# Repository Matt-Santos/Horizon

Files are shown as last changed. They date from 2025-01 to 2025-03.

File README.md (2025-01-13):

# Horizon (Planning Stage)

## Project Description
A high precision experimental bicopter with customized control system. 
 
## Research Hypothisis
A bicopter design when implemented using an unstable thrust to center of mass point can perform with equivalent mobility to that of the simlified quadcopter version through the use of an advanced control system. 

## Evaluation Criteria
To test this theory I purposely design an unstable thrust/weight configuration to enhance reactibility/mobility of the traditional bicopter configuration to avoid the added requirement of pitch control and improve overall efficiency.

## Todo List
- [ ] Perform Literature Review
- [ ] Identify Key Varriables
- [ ] Create Mathematical Model
- [ ] Perform Model Simulations
- [ ] Fabricate a Design Prototype
- [ ] Perform Experiemental Evaluation
- [ ] Create Publication of Findings

## Potential Usage Applications
- Atmospheric Monitoring
- Camera Mapping
- Antenna Testing

## Hardware Components
- [EMAX MT2213 935KV](https://emaxmodel.com/products/emax-mt2213-935kv-multicopter-brushless-motor) Multicopter Brushless Motor
- EMAX1045 Propeller
- [EMAX Simon Series 20A](https://emaxmodel.com/products/emax-simon-series-20a-for-muti-copter)

## Extra Notes

### Transport Canadian Drone Requirements

Note: Can avoid the AOL if takeoff weight is < 250g (goal)

Advanced Operations Licence (AOL)
- [ ] Advanced Drone Pilot Certificate
	- Pass Small Advanced Exam
	- Pass Flight Review
- [ ] Registered and Marked Drone
- [ ] RPAS Flight Authorization (for Controlled Airspace)
- [ ] RPAS Safety Declaration
	- Conforms to [Advisory Circular (AC) No. 922-001](https://tc.canada.ca/en/aviation/reference-centre/advisory-circulars/advisory-circular-ac-no-922-001)

Flight Restrictions (with AOL)
- Max Height AGL = 122m
- Operations in controlled and uncontrolled airspace
- Operations near people: less than 30 meters (100 feet) but more than 5 meters (16.4 feet) horizontally
- Operations over people: less than 5 meters (16.4 feet) horizontally
- Operations less than 3 nautical miles from a certified airport or a military aerodrome
- Operations less than 1 nautical mile from a certified heliport

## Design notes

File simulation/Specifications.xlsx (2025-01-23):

Current (A) | Thrust (G) | Power (W) | Efficiency (G/W) | Speed (RPM)
0.01 | 0 | 0 |  | 0
1 | 130 | 11 | 11.8 | 2940
2 | 220 | 22 | 10.0 | 3860
3 | 290 | 33 | 8.8 | 4400
4 | 360 | 44 | 8.2 | 4940
5 | 430 | 55 | 7.8 | 5340
6 | 490 | 66 | 7.4 | 5720
7 | 540 | 77 | 7.0 | 5980
8 | 580 | 88 | 6.6 | 6170
9 | 620 | 99 | 6.3 | 6410
9.5 | 640 | 105.5 | 6.1 | 6530
Note: Assumes drives voltage of 11.1V

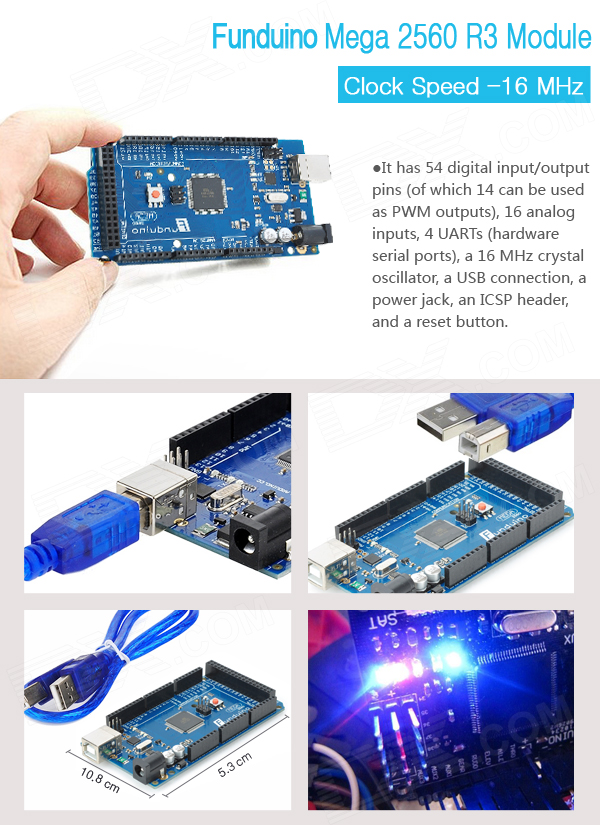
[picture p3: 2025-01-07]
documents/Refrences/sku_256335_01.jpg

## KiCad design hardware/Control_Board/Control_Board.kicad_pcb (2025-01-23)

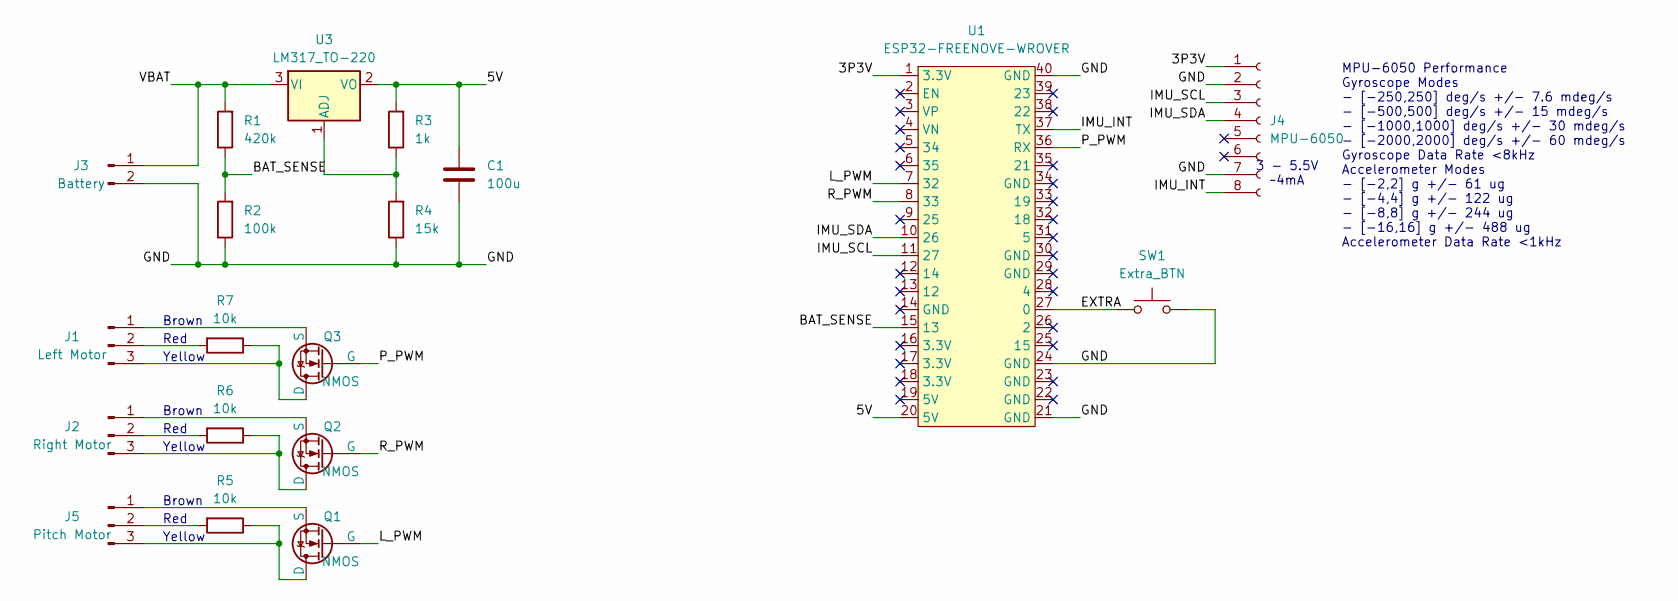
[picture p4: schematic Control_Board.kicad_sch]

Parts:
C1: 100u; C_Disc_D3.0mm_W1.6mm_P2.50mm
J1: Left Motor; PinHeader_1x03_P2.54mm_Vertical
J2: Right Motor; PinHeader_1x03_P2.54mm_Vertical
J3: Battery; PinHeader_1x02_P2.54mm_Vertical
J4: MPU-6050; PinSocket_1x08_P2.54mm_Vertical
J5: Pitch Motor; PinHeader_1x03_P2.54mm_Vertical
Q1, Q2, Q3: NMOS; PinHeader_1x03_P2.54mm_Vertical
R1: 420k; R_Axial_DIN0207_L6.3mm_D2.5mm_P10.16mm_Horizontal
R2: 100k; R_Axial_DIN0207_L6.3mm_D2.5mm_P10.16mm_Horizontal
R3: 1k; R_Axial_DIN0207_L6.3mm_D2.5mm_P10.16mm_Horizontal
R4: 15k; R_Axial_DIN0207_L6.3mm_D2.5mm_P10.16mm_Horizontal
R5, R6, R7: 10k; R_Axial_DIN0207_L6.3mm_D2.5mm_P10.16mm_Horizontal
SW1: Extra_BTN
U1: ESP32-FREENOVE-WROVER
U3: LM317_TO-220; TO-220-3_Vertical

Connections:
/3P3V: J4.1, U1.1 (3.3V)
/5V: C1.1, R3.2, U1.20 (5V), U3.2 (VO)
/BAT_SENSE: R1.1, R2.2, U1.15 (13)
/EXTRA: SW1.1, U1.27 (0)
/GND: C1.2, J3.2, J4.2, J4.7, R2.1, R4.1, SW1.2, U1.21 (GND), U1.24 (GND), U1.40 (GND)
/IMU_INT: J4.8, U1.37 (TX)
/IMU_SCL: J4.3, U1.11 (27)
/IMU_SDA: J4.4, U1.10 (26)
/L_PWM: Q1.2 (G), U1.7 (32)
/P_PWM: Q3.2 (G), U1.36 (RX)
/R_PWM: Q2.2 (G), U1.8 (33)
/VBAT: J3.1, R1.2, U3.3 (VI)
unnamed: J1.1, Q3.3 (S)
unnamed: J1.2, R7.2
unnamed: J1.3, Q3.1 (D), R7.1
unnamed: J2.1, Q2.3 (S)
unnamed: J2.2, R6.2
unnamed: J2.3, Q2.1 (D), R6.1
unnamed: J5.1, Q1.3 (S)
unnamed: J5.2, R5.2
unnamed: J5.3, Q1.1 (D), R5.1
unnamed: R3.1, R4.2, U3.1 (ADJ)

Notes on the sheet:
Brown
MPU-6050 Performance Gyroscope Modes - [-250,250] deg/s +/- 7.6 mdeg/s - [-500,500] deg/s +/- 15 mdeg/s - [-1000,1000] deg/s +/- 30 mdeg/s - [-2000,2000] deg/s +/- 60 mdeg/s Gyroscope Data Rate <8kHz Accelerometer Modes - [-2,2] g +/- 61 ug - [-4,4] g +/- 122 ug - [-8,8] g +/- 244 ug - [-16,16] g +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
Red
Yellow
3 - 5.5V ~4mA

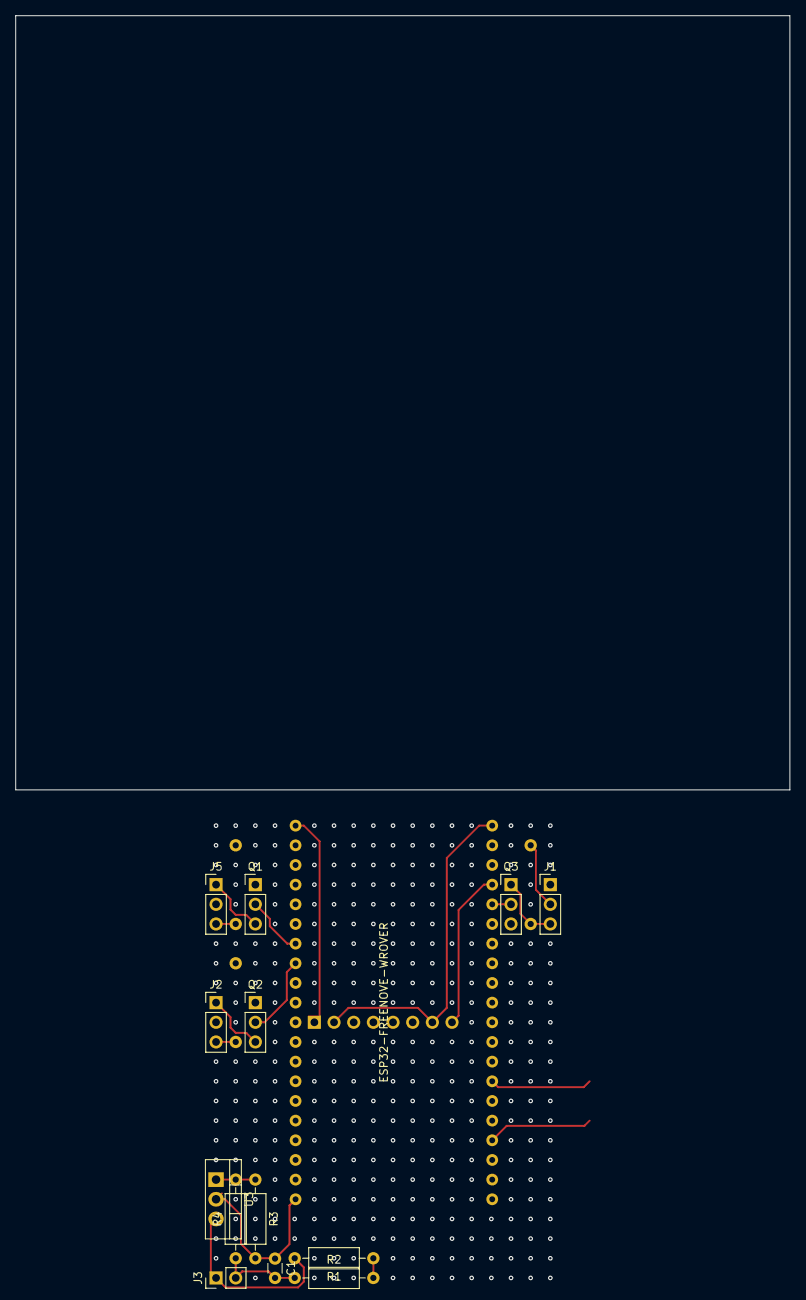
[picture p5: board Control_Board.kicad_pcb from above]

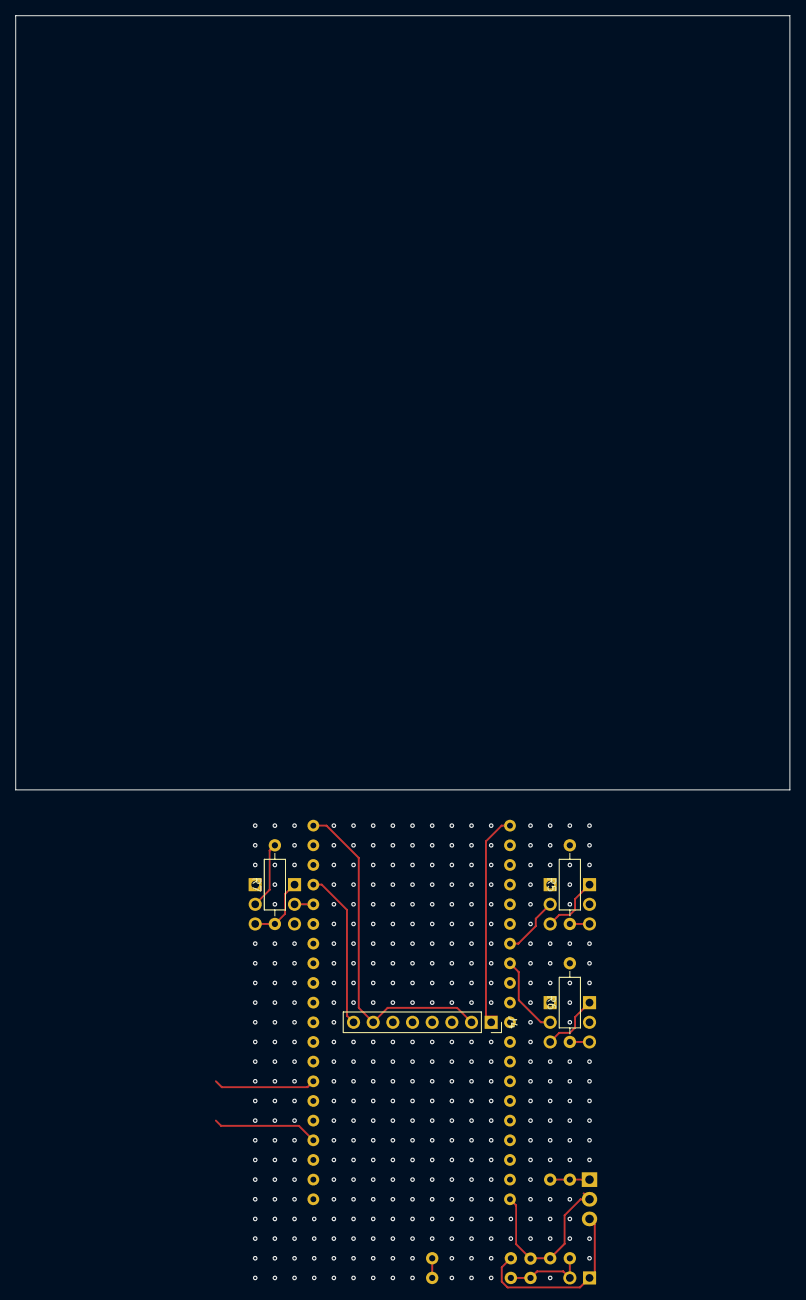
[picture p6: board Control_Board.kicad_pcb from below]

Board: 4 copper layers, 100.0 x 100.0 mm, 18 parts (4 on the bottom side), 21 nets.

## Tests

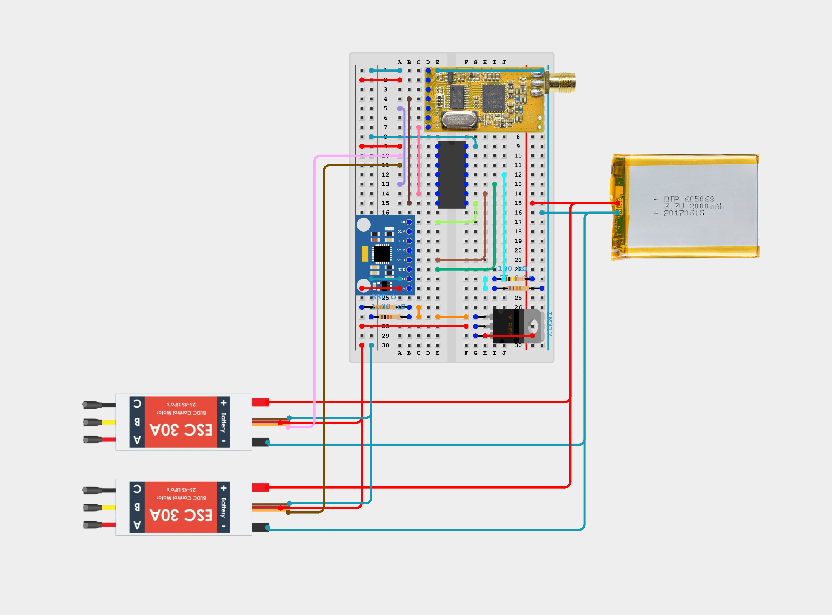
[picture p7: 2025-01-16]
hardware/Test_Board/Test_Board.png

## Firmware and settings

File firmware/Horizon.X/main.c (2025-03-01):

// Bicopter MPU Code
// Written by Matthew Santos

#include "mcc_generated_files/system/system.h"

//Program Functions
void SYSTEM_STARTUP(void);
void SYSTEM_UPDATE(void);
void APC220_Receiver_Interrupt(void);
void MPU_6050_Interrupt(void);
void ESC_Programming(uint8_t *settings);
uint16_t make16(uint8_t Left,uint8_t Right);

//Program Configuration
#define CMD_BYTES 			3
#define IMU_Addrs 			0x0068
#define IMU_Accel_Addrs 	0x3bu
#define IMU_Gyro_Addrs 		0x43u
#define IMU_Gyro_Range		0u	//0=250,1=500,2=1000,3=2000 [deg/s]
#define IMU_Accel_Range		0u	//0=2g,1=4g,2=8g,3=16g
#define BAT_Sense_Channel 	0x2
#define ESC_Brake			1
#define ESC_Timing			2
#define ESC_StartForce		1
#define ESC_CurveMode		1
#define ESC_CtrlFreq		2
#define ESC_LVProt			1
#define ESC_Cutoff			1
#define ESC_RotDir			1
#define ESC_nParameters		8

//Global Variables
char cmd[CMD_BYTES];
struct {
    bool UART_Data;
    bool IMU_Data;
    bool BAT_Data;
} Flags = {0,0,0};
uint16_t BAT_LEVEL = 0;
struct {
	uint8_t accel[6];
	uint8_t gyro[6];
} IMU_Data;
uint8_t ESC_Setting[ESC_nParameters] = {
	ESC_Brake,
	ESC_Timing,
	ESC_StartForce,
	ESC_CurveMode,
	ESC_CtrlFreq,
	ESC_LVProt,
	ESC_Cutoff,
	ESC_RotDir
};

//Main Program
int main(void){
    SYSTEM_Initialize();
    //Test Program
    //------------------
    while(1){
        BAT_LEVEL = (ADC_GetConversion(BAT_SENSE)>>6);
        //1024 = max
        PWM3_LoadDutyValue(BAT_LEVEL);
        PWM4_LoadDutyValue(BAT_LEVEL);
    }
    
    
    
    //------------------
    //Main Program
    SYSTEM_STARTUP();
    while(1){
        SYSTEM_UPDATE();
        //Note Battery still needs a trigger
    }
}

//Support Functions
//---------------------

//Perform Startup Procedure
void SYSTEM_STARTUP(void){
    //Disable Interrupts
    INTERRUPT_GlobalInterruptDisable(); 
    INTERRUPT_PeripheralInterruptDisable(); 
    
    //Setup UART Communications
    EUSART_Enable();
	EUSART_RxCompleteCallbackRegister(APC220_Receiver_Interrupt);
	EUSART_ReceiveInterruptEnable();
	EUSART_ReceiveEnable();
	//EUSART_TxCompleteCallbackRegister();
    EUSART_TransmitInterruptEnable();
	EUSART_TransmitEnable();
	
	//Setup IMU
/*	uint8_t config[4] = [
		0x1a, //Start Register Address
		0x00,	//CONFIG
		IMU_Gyro_Range<<3,	//GYRO_CONFIG
		IMU_Gyro_Range<<3,	//ACCEL_CONFIG
		];
	I2C1_Write(IMU_Addrs,config, 4);
	INT_IMU_SetInterruptHandler(MPU_6050_Interrupt);
    */
    //Enable Interrupts
    INTERRUPT_GlobalInterruptEnable();
    INTERRUPT_PeripheralInterruptEnable();
	
	//Startup Delay
	__delay_ms(1000);
	printf("Ready\r\n");
}

//Performs System Updates
void SYSTEM_UPDATE(void){
    if(Flags.UART_Data){  //Process Received UART Command
        switch(cmd[0]){
            case 'L':   //Set Left Motor PWM
                PWM3_LoadDutyValue(make16(cmd[2],cmd[1]));
                break;
            case 'R':   //Set Right Motor PWM
                PWM4_LoadDutyValue(make16(cmd[2],cmd[1]));
                break;
            case 'E':   //Enable ESC
                ESC_EN_SetHigh();
				printf("ESC Enabled\r\n");
                break;
            case 'e':   //Disable ESC
                ESC_EN_SetLow();
				printf("ESC Disabled\r\n");
                break;
			case 'P':	//Program/Calibrate ESC
                printf("ESC Programming Start\r\n");
				ESC_Programming(ESC_Setting);
				printf("ESC Programming Complete\r\n");
				break;
            case 'B':   //Print Battery Level
                printf("%u",BAT_LEVEL);
                break;
			case 'I':	//Enable IMU Output Stream
				EXT_INT_InterruptEnable();
				printf("IMU Stream Enabled\r\n");
				break;
			case 'i':	//Disable IMU Output Stream
				EXT_INT_InterruptDisable();
				printf("IMU Stream Disabled\r\n");
				break;
            default:
				printf("CMD not Recognized\r\n");
                break;
        }
        Flags.UART_Data = 0;
    }
    else if(Flags.IMU_Data){
        //Get New IMU Data
        //I2C1_WriteRead(IMU_Addrs,IMU_Accel_Addrs,1,IMU_Data.accel,6);
        //I2C1_WriteRead(IMU_Addrs,IMU_Gyro_Addrs,1,IMU_Data.gyro,6);
        //Format IMU Data for Transmission
        int16_t ax = (int16_t) make16(IMU_Data.accel[0],IMU_Data.accel[1]);
        int16_t ay = (int16_t) make16(IMU_Data.accel[2],IMU_Data.accel[3]);
        int16_t az = (int16_t) make16(IMU_Data.accel[4],IMU_Data.accel[5]);
        int16_t x = (int16_t) make16(IMU_Data.gyro[0],IMU_Data.gyro[1]);
        int16_t y = (int16_t) make16(IMU_Data.gyro[2],IMU_Data.gyro[3]);
        int16_t z = (int16_t) make16(IMU_Data.gyro[4],IMU_Data.gyro[5]);
        //Send New IMU Data
        printf("%d,%d,%d,%d,%d,%d",x,y,z,ax,ay,az);
        Flags.IMU_Data = 0;
    }
    else if(Flags.BAT_Data){
        BAT_LEVEL = ADC_GetConversion(BAT_SENSE);	//Update Battery Data
        Flags.BAT_Data = 0;
    }
}
//APC220_Receiver_Interrupt
void APC220_Receiver_Interrupt(void){
	static uint8_t index = 0;   //Tracks Last Entry
    char msg = EUSART_Read();
    if(msg == '\r'){    //Execute Stored Command
        Flags.UART_Data = 1;
        index = 0;
    }
    else{	//Store CMD Data and Increment Index
        cmd[index] = msg;
		index = (index + 1) % CMD_BYTES;
    }
}

//MPU_6050_Interrupt
void MPU_6050_Interrupt(void){
    Flags.IMU_Data = 1;
}

//ESC Programming Mode
void ESC_Programming(uint8_t *settings){
	//Reset the ESC
    printf("Reseting ESCs\r\n");
	ESC_EN_SetLow();
	__delay_ms(2000);
	//Startup in Throttle Setting Mode
	PWM3_LoadDutyValue(0xFFFF);
	PWM4_LoadDutyValue(0xFFFF);
	__delay_ms(100);
    printf("Powering on ESCs\r\n");
	ESC_EN_SetHigh();
	//Set Max Throttle
	__delay_ms(2000); 	// (2x) beep
	//Enter Programming Mode
    printf("Entering Programming Mode\r\n");
	__delay_ms(2000);	// beep 123 123
	//Program All Parameters
	for (uint8_t i = 0; i < ESC_nParameters;i++){
        printf("Programming Parameter %u\r\n",i);
		//Select Next Parameter
        for (int c=0;c<i;c++)
            __delay_ms(1000);	
		PWM3_LoadDutyValue(0x0000);
		PWM4_LoadDutyValue(0x0000);
		//Select Parameter Value Option
        for (int c=0;c<settings[i];c++)
            __delay_ms(1000);
		PWM3_LoadDutyValue(0xFFFF);
		PWM4_LoadDutyValue(0xFFFF);
	}
	//Exit Programming Mode
	__delay_ms(1000);
	PWM3_LoadDutyValue(0x0000);
	PWM4_LoadDutyValue(0x0000);
	__delay_ms(2000);
}

//Combine two 8bit registers into a 16bit
uint16_t make16(uint8_t Left,uint8_t Right){
    uint16_t result = ((uint16_t) Left ) << 8;
    return result | Right;
}

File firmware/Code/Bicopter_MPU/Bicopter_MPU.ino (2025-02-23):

// Bicopter Firmware
// Written by Matthew Santos

//Libraries
#include "storage_system.h"
#include "sensor_system.h"
#include "network_system.h"
#include "comms_system.h"
#include "flight_system.h"

/* Todo

-storage class
  -verify NVS
  -add additional SDCard functions and test

-sensor class
  -Perfect IMU Offset Calibration, orientation/frame directionality and Filtering
  -Increase GPS SampleRate and optimize messages
  -Use pressure Sensor for altitude complementary filter
  -Calibrate the Battery Sensor (and send to comms)
  -improve camera system? (or just leave it to the network stack)
  
-network class
  -configure the camera webserver and setup vlc to perform local GCS conversion/encoding of video feed to qGCS

-comms class
  -arming ability (starts by giving ESC minimal throttle (to calibrate) in Comms)
  -change control modes
  -complete FTP Protocal and Metadata delivery

-flight class
  -Implement Pitch Motor Calibration
  -Perfect ESC Motor Calibration
  -Implement stabilization PID system with storaged values

-Note ESP32 Has two processors and could benifit from multithreading (flight calculations)
*/

//Debug Flags
// #define TIME_Debug

//System Modules (Global Objects)
Flight_System *flight = new Flight_System();
Storage_System *storage = new Storage_System();
Sensor_System *sensor = new Sensor_System();
Network_System *network = new Network_System();
Comms_System *comms = new Comms_System();

//Startup
void setup() {
  Serial.begin(115200,SERIAL_8N1);
  while (!Serial){}Serial.println("Starting Up");
  flight->Init();
  storage->Init();
  sensor->Init();
  network->Init();
  comms->Init();
}

//Main Program Loop
void loop() {
  #ifdef TIME_Debug
    static unsigned long last[5];
    last[0] = micros(); flight->Update();   Serial.printf("Flight_t:%d,",micros()-last[0]);
    last[1] = micros(); sensor->Update();   Serial.printf("Sensor_t:%d,",micros()-last[1]);
    last[2] = micros(); network->Update();  Serial.printf("Network_t:%d,",micros()-last[2]);
    last[3] = micros(); comms->Update();    Serial.printf("Comms_t:%d,",micros()-last[3]);
    
    Serial.printf("Loop_Delay[us]:%d\n",micros()-last[4]);
    last[4] = micros();
  #else
    flight->Update();
    sensor->Update();
    network->Update();
    comms->Update();
  #endif
}

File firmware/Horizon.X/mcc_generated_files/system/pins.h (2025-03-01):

/**
 * Generated Pins header File
 * 
 * @file pins.h
 * 
 * @defgroup  pinsdriver Pins Driver
 * 
 * @brief This is generated driver header for pins. 
 *        This header file provides APIs for all pins selected in the GUI.
 *
 * @version Driver Version  3.0.0
*/

/*
© [2025] Microchip Technology Inc. and its subsidiaries.

    Subject to your compliance with these terms, you may use Microchip 
    software and any derivatives exclusively with Microchip products. 
    You are responsible for complying with 3rd party license terms  
    applicable to your use of 3rd party software (including open source  
    software) that may accompany Microchip software. SOFTWARE IS ?AS IS.? 
    NO WARRANTIES, WHETHER EXPRESS, IMPLIED OR STATUTORY, APPLY TO THIS 
    SOFTWARE, INCLUDING ANY IMPLIED WARRANTIES OF NON-INFRINGEMENT,  
    MERCHANTABILITY, OR FITNESS FOR A PARTICULAR PURPOSE. IN NO EVENT 
    WILL MICROCHIP BE LIABLE FOR ANY INDIRECT, SPECIAL, PUNITIVE, 
    INCIDENTAL OR CONSEQUENTIAL LOSS, DAMAGE, COST OR EXPENSE OF ANY 
    KIND WHATSOEVER RELATED TO THE SOFTWARE, HOWEVER CAUSED, EVEN IF 
    MICROCHIP HAS BEEN ADVISED OF THE POSSIBILITY OR THE DAMAGES ARE 
    FORESEEABLE. TO THE FULLEST EXTENT ALLOWED BY LAW, MICROCHIP?S 
    TOTAL LIABILITY ON ALL CLAIMS RELATED TO THE SOFTWARE WILL NOT 
    EXCEED AMOUNT OF FEES, IF ANY, YOU PAID DIRECTLY TO MICROCHIP FOR 
    THIS SOFTWARE.
*/

#ifndef PINS_H
#define PINS_H

#include <xc.h>

#define INPUT   1
#define OUTPUT  0

#define HIGH    1
#define LOW     0

#define ANALOG      1
#define DIGITAL     0

#define PULL_UP_ENABLED      1
#define PULL_UP_DISABLED     0

// get/set IO_RA2 aliases
#define BAT_SENSE_TRIS                 TRISAbits.TRISA2
#define BAT_SENSE_LAT                  LATAbits.LATA2
#define BAT_SENSE_PORT                 PORTAbits.RA2
#define BAT_SENSE_WPU                  WPUAbits.WPUA2
#define BAT_SENSE_OD                   ODCONAbits.ODA2
#define BAT_SENSE_ANS                  ANSELAbits.ANSA2
#define BAT_SENSE_SetHigh()            do { LATAbits.LATA2 = 1; } while(0)
#define BAT_SENSE_SetLow()             do { LATAbits.LATA2 = 0; } while(0)
#define BAT_SENSE_Toggle()             do { LATAbits.LATA2 = ~LATAbits.LATA2; } while(0)
#define BAT_SENSE_GetValue()           PORTAbits.RA2
#define BAT_SENSE_SetDigitalInput()    do { TRISAbits.TRISA2 = 1; } while(0)
#define BAT_SENSE_SetDigitalOutput()   do { TRISAbits.TRISA2 = 0; } while(0)
#define BAT_SENSE_SetPullup()          do { WPUAbits.WPUA2 = 1; } while(0)
#define BAT_SENSE_ResetPullup()        do { WPUAbits.WPUA2 = 0; } while(0)
#define BAT_SENSE_SetPushPull()        do { ODCONAbits.ODA2 = 0; } while(0)
#define BAT_SENSE_SetOpenDrain()       do { ODCONAbits.ODA2 = 1; } while(0)
#define BAT_SENSE_SetAnalogMode()      do { ANSELAbits.ANSA2 = 1; } while(0)
#define BAT_SENSE_SetDigitalMode()     do { ANSELAbits.ANSA2 = 0; } while(0)
// get/set IO_RA4 aliases
#define R_PWM_TRIS                 TRISAbits.TRISA4
#define R_PWM_LAT                  LATAbits.LATA4
#define R_PWM_PORT                 PORTAbits.RA4
#define R_PWM_WPU                  WPUAbits.WPUA4
#define R_PWM_OD                   ODCONAbits.ODA4
#define R_PWM_ANS                  ANSELAbits.ANSA4
#define R_PWM_SetHigh()            do { LATAbits.LATA4 = 1; } while(0)
#define R_PWM_SetLow()             do { LATAbits.LATA4 = 0; } while(0)
#define R_PWM_Toggle()             do { LATAbits.LATA4 = ~LATAbits.LATA4; } while(0)
#define R_PWM_GetValue()           PORTAbits.RA4
#define R_PWM_SetDigitalInput()    do { TRISAbits.TRISA4 = 1; } while(0)
#define R_PWM_SetDigitalOutput()   do { TRISAbits.TRISA4 = 0; } while(0)
#define R_PWM_SetPullup()          do { WPUAbits.WPUA4 = 1; } while(0)
#define R_PWM_ResetPullup()        do { WPUAbits.WPUA4 = 0; } while(0)
#define R_PWM_SetPushPull()        do { ODCONAbits.ODA4 = 0; } while(0)
#define R_PWM_SetOpenDrain()       do { ODCONAbits.ODA4 = 1; } while(0)
#define R_PWM_SetAnalogMode()      do { ANSELAbits.ANSA4 = 1; } while(0)
#define R_PWM_SetDigitalMode()     do { ANSELAbits.ANSA4 = 0; } while(0)
// get/set IO_RA5 aliases
#define L_PWM_TRIS                 TRISAbits.TRISA5
#define L_PWM_LAT                  LATAbits.LATA5
#define L_PWM_PORT                 PORTAbits.RA5
#define L_PWM_WPU                  WPUAbits.WPUA5
#define L_PWM_OD                   ODCONAbits.ODA5
#define L_PWM_ANS                  ANSELAbits.
#define L_PWM_SetHigh()            do { LATAbits.LATA5 = 1; } while(0)
#define L_PWM_SetLow()             do { LATAbits.LATA5 = 0; } while(0)
#define L_PWM_Toggle()             do { LATAbits.LATA5 = ~LATAbits.LATA5; } while(0)
#define L_PWM_GetValue()           PORTAbits.RA5
#define L_PWM_SetDigitalInput()    do { TRISAbits.TRISA5 = 1; } while(0)
#define L_PWM_SetDigitalOutput()   do { TRISAbits.TRISA5 = 0; } while(0)
#define L_PWM_SetPullup()          do { WPUAbits.WPUA5 = 1; } while(0)
#define L_PWM_ResetPullup()        do { WPUAbits.WPUA5 = 0; } while(0)
#define L_PWM_SetPushPull()        do { ODCONAbits.ODA5 = 0; } while(0)
#define L_PWM_SetOpenDrain()       do { ODCONAbits.ODA5 = 1; } while(0)
#define L_PWM_SetAnalogMode()      do { ANSELAbits. = 1; } while(0)
#define L_PWM_SetDigitalMode()     do { ANSELAbits. = 0; } while(0)
// get/set IO_RC0 aliases
#define IO_RC0_TRIS                 TRISCbits.TRISC0
#define IO_RC0_LAT                  LATCbits.LATC0
#define IO_RC0_PORT                 PORTCbits.RC0
#define IO_RC0_WPU                  WPUCbits.WPUC0
#define IO_RC0_OD                   ODCONCbits.ODC0
#define IO_RC0_ANS                  ANSELCbits.ANSC0
#define IO_RC0_SetHigh()            do { LATCbits.LATC0 = 1; } while(0)
#define IO_RC0_SetLow()             do { LATCbits.LATC0 = 0; } while(0)
#define IO_RC0_Toggle()             do { LATCbits.LATC0 = ~LATCbits.LATC0; } while(0)
#define IO_RC0_GetValue()           PORTCbits.RC0
#define IO_RC0_SetDigitalInput()    do { TRISCbits.TRISC0 = 1; } while(0)
#define IO_RC0_SetDigitalOutput()   do { TRISCbits.TRISC0 = 0; } while(0)
#define IO_RC0_SetPullup()          do { WPUCbits.WPUC0 = 1; } while(0)
#define IO_RC0_ResetPullup()        do { WPUCbits.WPUC0 = 0; } while(0)
#define IO_RC0_SetPushPull()        do { ODCONCbits.ODC0 = 0; } while(0)
#define IO_RC0_SetOpenDrain()       do { ODCONCbits.ODC0 = 1; } while(0)
#define IO_RC0_SetAnalogMode()      do { ANSELCbits.ANSC0 = 1; } while(0)
#define IO_RC0_SetDigitalMode()     do { ANSELCbits.ANSC0 = 0; } while(0)
// get/set IO_RC1 aliases
#define IO_RC1_TRIS                 TRISCbits.TRISC1
#define IO_RC1_LAT                  LATCbits.LATC1
#define IO_RC1_PORT                 PORTCbits.RC1
#define IO_RC1_WPU                  WPUCbits.WPUC1
#define IO_RC1_OD                   ODCONCbits.ODC1
#define IO_RC1_ANS                  ANSELCbits.ANSC1
#define IO_RC1_SetHigh()            do { LATCbits.LATC1 = 1; } while(0)
#define IO_RC1_SetLow()             do { LATCbits.LATC1 = 0; } while(0)
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

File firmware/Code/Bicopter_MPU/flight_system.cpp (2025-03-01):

//Bicopter Flight System
//Written by Matthew Santos

#include "flight_system.h"
#include "sensor_system.h"
#include "comms_system.h"

//Debug Flags
#define MOTOR_Debug
#define MODE_Debug

//I2C Interface
#define I2C_SDA         26      //I2C Data Pin
#define I2C_SCL         27      //I2C Clock Pin
#define I2C_Freq        400000  //[Hz] I2C Clock Frequency

//Motor Settings (MOTOR)
#define PCA9685_Addrs     0x40  //PCA9685 I2C Address
#define Motor_OE_Pin      32    //PCA9685 Output Enable Pin
#define PWM_Frequency     50    //[Hz] PWM Output Frequency
#define L_Motor_Chan      0     //Left  Motor Output Channel
#define R_Motor_Chan      1     //Right Motor Output Channel
#define P_Motor_ChanE     2     //Pitch Motor Enable
#define P_Motor_ChanA1    4     //Pitch Motor Output Channel A1
#define P_Motor_ChanA2    5     //Pitch Motor Output Channel A2
#define P_Motor_ChanB1    7     //Pitch Motor Output Channel B1
#define P_Motor_ChanB2    6     //Pitch Motor Output Channel B2
#define P_Motor_Tol       1     //[%] Pitch Motor Control Tolerene
#define P_Motor_Count     500   //Number of Pulses to travel Full Pitch Motor Range
#define PWM_MIN           5     //Minimum PWM Output
#define PWM_MAX           10    //Maximum PWM Output
#define P_Motor_MIN       5     //Minimum Pitch Motor Position
#define P_Motor_MAX       95    //Maximum Pitch Motor Position

extern Sensor_System *sensor;
extern Comms_System *comms;

//Motor Control (MOTOR)
//---------------------
bool Flight_System::MOTOR_Init(){
  bool success = true;
  //Configure I2C Interface
  pinMode(I2C_SDA,INPUT_PULLUP);
  pinMode(I2C_SCL,INPUT_PULLUP);
  success &= Wire.begin(I2C_SDA,I2C_SCL,I2C_Freq);
  //Setup Motor PWM Driver
  motor.setupSingleDevice(Wire,PCA9685_Addrs);
  motor.setupOutputEnablePin(Motor_OE_Pin);
  motor.setToFrequency(PWM_Frequency);
  motor.setOutputsLowWhenDisabled();
  motor.disableOutputs(Motor_OE_Pin);
  motor.setOutputsInverted();
  // motor.setOutputsNotInverted();
  //Set Pitch Motor to Initially Disabled
  motor.setChannelDutyCycle(P_Motor_ChanE,0);
  //Calibrate Motors
  MOTOR_ESC_Calibrate();
  MOTOR_Pitch_Calibrate();
  return success;
}
void Flight_System::MOTOR_ESC_Calibrate(){
  //Calibrate ESC Throttle Max
  motor.setChannelDutyCycle(L_Motor_Chan,PWM_MAX);
  motor.setChannelDutyCycle(R_Motor_Chan,PWM_MAX);
  motor.enableOutputs(Motor_OE_Pin);
  delay(4500);  //Wait for two beeps
  //Calibrate ESC Throttle Min
  motor.setChannelDutyCycle(L_Motor_Chan,PWM_MIN);
  motor.setChannelDutyCycle(R_Motor_Chan,PWM_MIN);
  //Shutdown ESC
  delay(5000);
}
void Flight_System::MOTOR_Pitch_Calibrate(){
  //Force Pitch Motor to Zero Point
  motor.setChannelDutyCycle(P_Motor_ChanE,100);
  int count = 0;
  while(count<P_Motor_Count){
    count += MOTOR_Pitch_Control(100 + 2*P_Motor_Tol);
  }
  //Set Initial Pitch Position to Midpoint
  count = 0;
  while(count<(P_Motor_Count/2)){
    count += MOTOR_Pitch_Control(50);
  }
  //Disable Pitch Motor
  motor.setChannelDutyCycle(P_Motor_ChanE,0);
}
bool Flight_System::MOTOR_Pitch_Control(float target){
  static float position = 50;     //[%] Motor Position as % of Range
  static unsigned long last;      //[us] Time between Function Calls
  static bool enabled = false;
  static uint8_t index = 0;

  //Limit Servo RotationSpeed
  if(micros()-last < 10000) return false;

  //Update Direction
  bool forwards = position < target;

  //Enable Control
  if(position < target - P_Motor_Tol || position > target + P_Motor_Tol){
    if(!enabled){
      motor.setChannelDutyCycle(P_Motor_ChanE,100);
      enabled = true;
    }
    //Update Position
    position -= 100.0/P_Motor_Count*(1-2*forwards);
    position = constrain(position,0.0,100.0);
  }
  else{
    motor.setChannelDutyCycle(P_Motor_ChanE,0);
    enabled = false;
  }

  //Update State
  index = (index+1) % 8;
  switch(index){
    case 0:
      if(forwards){
        motor.setChannelDutyCycle(P_Motor_ChanB2,0);
      }
      else{
        motor.setChannelDutyCycle(P_Motor_ChanB1,0);
      }
      break;
    case 1:
      if(forwards){
        motor.setChannelDutyCycle(P_Motor_ChanB1,100);
      }
      else{
        motor.setChannelDutyCycle(P_Motor_ChanB2,100);
      }
      break;
    case 2:
      motor.setChannelDutyCycle(P_Motor_ChanA1,0);
      break;
    case 3:
      motor.setChannelDutyCycle(P_Motor_ChanA2,100);
      break;
    case 4:
      if(forwards){
        motor.setChannelDutyCycle(P_Motor_ChanB1,0);
      }
      else{
        motor.setChannelDutyCycle(P_Motor_ChanB2,0);
      }
      break;
    case 5:
      if(forwards){
        motor.setChannelDutyCycle(P_Motor_ChanB2,100);
      }
      else{
        motor.setChannelDutyCycle(P_Motor_ChanB1,100);
      }
      break;
    case 6:
      motor.setChannelDutyCycle(P_Motor_ChanA2,0);
      break;
    case 7:
      motor.setChannelDutyCycle(P_Motor_ChanA1,100);
      break;
  }
  #ifdef MOTOR_Debug
    Serial.printf("Pitch_Position:%f\n",position);
  #endif
  last = micros();
  return true;
}
void Flight_System::MOTOR_Update(){
  if (ARMED){
    //Update Motor Positions
    motor.setChannelDutyCycle(L_Motor_Chan,L_Motor);
    motor.setChannelDutyCycle(R_Motor_Chan,R_Motor);
    MOTOR_Pitch_Control(P_Motor);
  }
  else{
    //Set ESC Throttle to Zero
    motor.setChannelDutyCycle(L_Motor_Chan,PWM_MIN);
    motor.setChannelDutyCycle(R_Motor_Chan,PWM_MIN);
  }
  
  #ifdef MOTOR_Debug
    Serial.printf("L:%f,R:%f,P:%f,ARM:%d\n",L_Motor,R_Motor,P_Motor,ARMED);
  #endif
}

//Flight Control Modes (MODE)
//--------------------------
bool Flight_System::MODE_Init(){

  return true;
}
void Flight_System::MODE_Update(){
  //Obtain Flight Orders
  switch(flight_mode){
    case MODE_MANUAL:
      L_Motor = ((comms->MAVLINK_manual_control.z/10.0)-(comms->MAVLINK_manual_control.y/10.0))*(PWM_MAX-PWM_MIN)/100.0+PWM_MIN;
      R_Motor = ((comms->MAVLINK_manual_control.z/10.0)+(comms->MAVLINK_manual_control.y/10.0))*(PWM_MAX-PWM_MIN)/100.0+PWM_MIN;
      P_Motor = (comms->MAVLINK_manual_control.x/20.0+50);  //[0 to 100]
      break;
    case MODE_HOLD_ALT:
      break;
    case MODE_STABILIZE:
      break;
    case MODE_AUTO:
      break;
    case MODE_CIRCLE:
      break;
    case MODE_DRIFT:
      break;
    case MODE_GUIDED:
      break;
    case MODE_LAND:
      break;
    case MODE_TAKEOFF:
      break;
    case MODE_HOLD_POS:
      break;
  }
  //Set Control Limits
  L_Motor = constrain(L_Motor,PWM_MIN,PWM_MAX);
  R_Motor = constrain(R_Motor,PWM_MIN,PWM_MAX);
  P_Motor = constrain(P_Motor,P_Motor_MIN,P_Motor_MAX);

  #ifdef MODE_Debug
    Serial.printf("x:%d,",comms->MAVLINK_manual_control.x);
    Serial.printf("y:%d,",comms->MAVLINK_manual_control.y);
    Serial.printf("z:%d\n",comms->MAVLINK_manual_control.z);
  #endif
}

//Flight System Class 
//--------------------------
void Flight_System::Init(){
  if(!MOTOR_Init()) Serial.println("Error Initializing Flight->Motor");
  if(!MODE_Init())  Serial.println("Error Initializing Flight->Mode");
}
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

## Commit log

2025-01-13 feat: project readme + add references
    [Specifications.xlsx, frame.FCStd]
2025-01-15 feat: created basic control board schematic
    [Control_Board.kicad_pcb, Control_Board.kicad_sch]
2025-01-16 feat: create initial test board
    [Control_Board.kicad_sch]
2025-01-23 feat: update prototype with esp32
    [Control_Board.kicad_pcb, Control_Board.kicad_sch, Specifications.xlsx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]
2025-01-27 feat: update and reorganize MPU Code
    [Control_Board.kicad_sch, config_data.xlsx, pin_configuration.xlsx]
2025-01-30 fix: started code refactoring
    [config_data.xlsx]
2025-01-31 fix: save state before next refactor attempt
    [Bicopter_MPU.ino, comms_system.cpp, flight_system.cpp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]
2025-02-02 feat: added filtering to IMU sensor readings
2025-02-05 feat: completed PWM calibration procedure
2025-02-07 feat: upgraded imu code
    [815 Servo Driver 16 Channel.step, BMP180 Breakout.step, Control_Board.kicad_sch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]
2025-02-13 feat: update sensor system
    [815 Servo Driver 16 Channel.step, BMP180 Breakout.step, Enclosure.FCStd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]
2025-02-16 feat: added pitch servo control
2025-02-17 feat: pitch control via direct stepping
2025-02-19 feat: improve servo control
2025-02-23 fix: motor controls with new offsets
    [Bicopter_MPU.ino, flight_system.cpp, flight_system.h]
